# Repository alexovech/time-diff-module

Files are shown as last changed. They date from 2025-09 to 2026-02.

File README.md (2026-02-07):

# LapTimer – Subtraction Module

Team of 5 students.  
My role: subtraction module designer.  
Developed the subtraction module responsible for calculating the time difference between two stopwatch readings.  

---

## Overview
- **Full project description:** [Overview](docs/overview.md)
- **Skills Developed:** Working with Multisim and Ultiboard, designing and testing digital circuits, debugging BCD subtraction logic, and optimizing PCB layout.
- **Features:** BCD-based subtraction, carry/borrow correction, RC-delay capture, setting values through D-type flip-flops and 7-segment display output.
- **Technology:** Texas Instruments 74LS series logic (Full Adders, Flip-Flops, Inverters, XOR/AND/NOR gates).
- **Simulation & PCB:** Designed in [Multisim](schematic/multisim) and [Ultiboard](schematic/pcb) (with 3D projection).

---

## Photo Demonstration
Circuit in Multisim:  
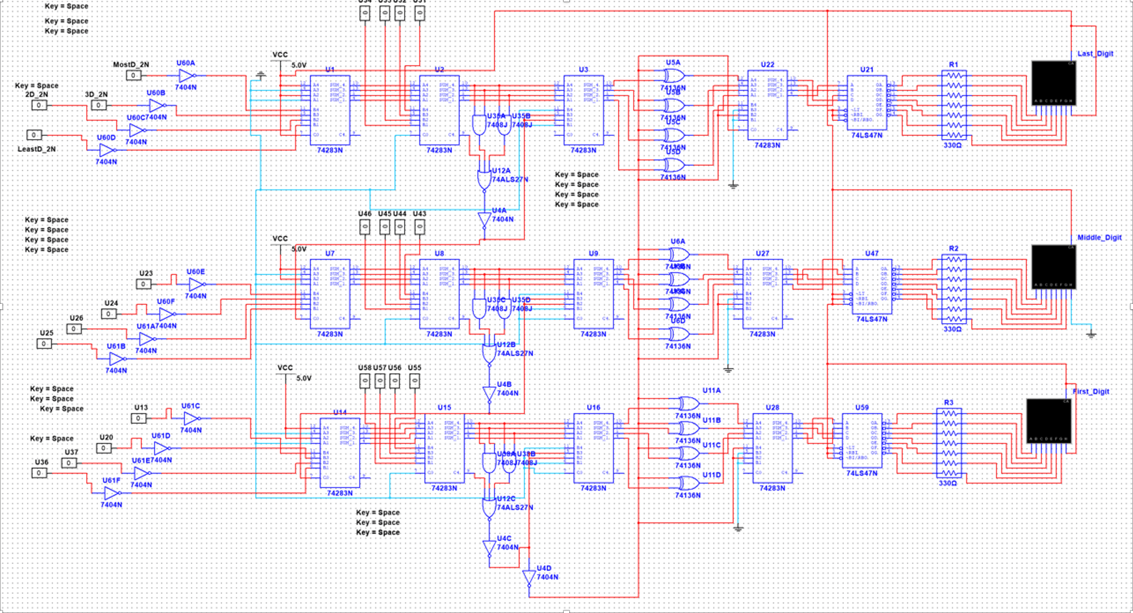
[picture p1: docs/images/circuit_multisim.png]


PCB 3D view (Ultiboard):  
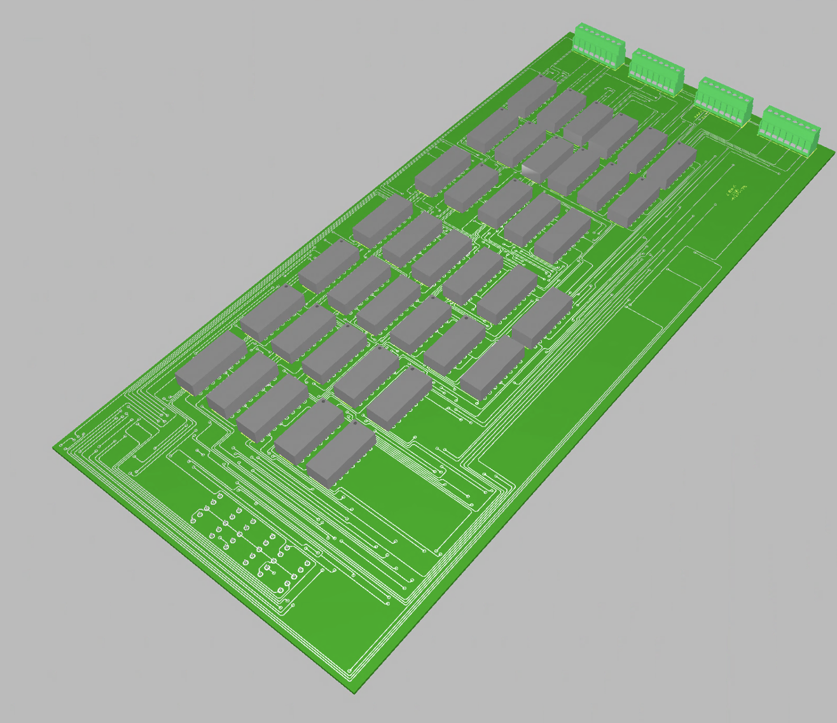
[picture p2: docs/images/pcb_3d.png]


---

## Video Demonstration
System in Action: [▶ Watch on YouTube](https://youtu.be/WPylpVr9RIs)

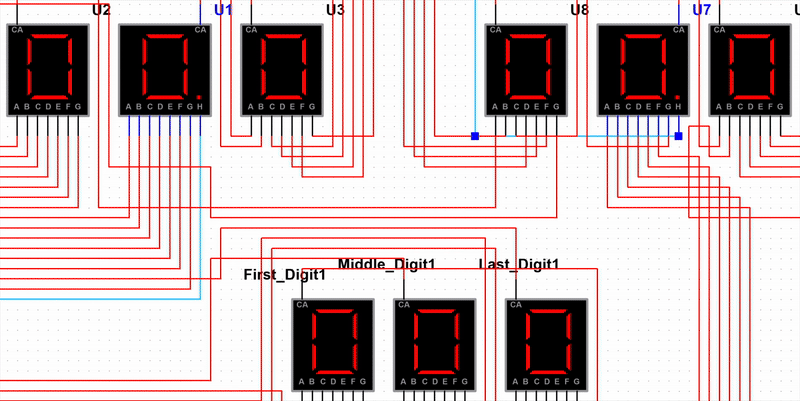
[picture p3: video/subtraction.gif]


---

## Problem-Solving Process
**Full list of challenges and their sollutions:** [Problems & Solutions](docs/problems_solutions.md)

**Example of handwritten notes:**
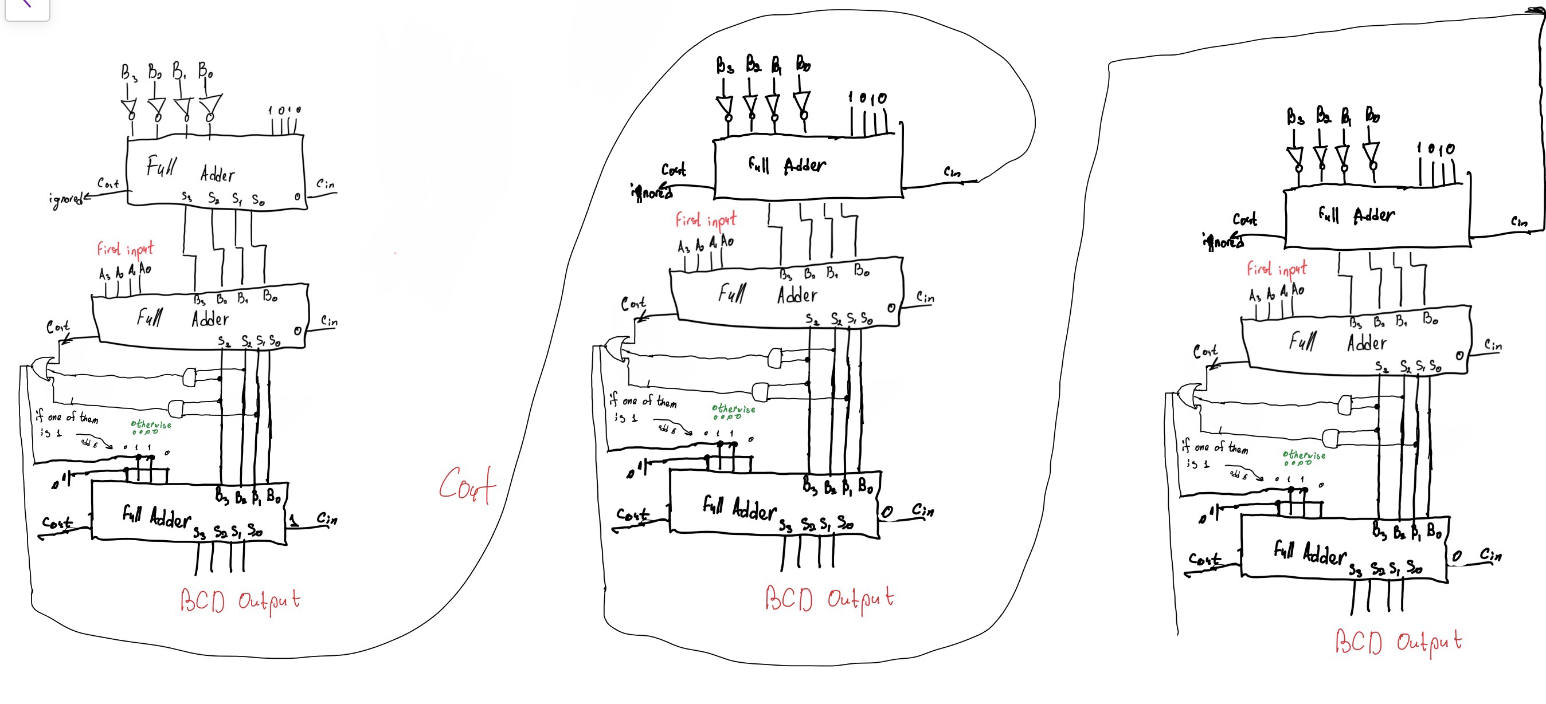
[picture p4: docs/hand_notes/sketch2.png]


➡️ [View rest early calculations and design notes here](docs/hand_notes)

---

## Future Improvements
At this point in development, one of the chief weaknesses in the circuit remains its size.

As this project was done in year one, when both high-level programming concepts and low-level programming concepts had not yet been introduced in class,
The design was purely dependent on hardware logic based on 74LS-series ICs.
But there are quite a few ways in which this system can be improved and minimized in the future:

1. **Microcontroller Integration**

One possible enhancement could be to use a **microcontroller** (like Arduino or ATmega) to create the subtraction logic.
This would enable a single logic IC to replace multifaceted logic ICs. It was intended to simplify wiring and reduce board sizes.

2. **Implementation using VHDL on a PLD/CPLD**

One possible solution using logic design re-engineering would involve redesigning using **Hardware Description Language (VHDL)** to run the logic design on a **programmable logic device (PLD or CPLD)**. This solution would retain the same digital logic design structure for the original project but would improve its speed performance. but with a far smaller footprint, so that everything remains purely hardware-based.

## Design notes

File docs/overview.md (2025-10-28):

The project is a digital stopwatch system for measuring the race laps. The system consists of several interlinked circuits in which every circuit is specially designed to have a specific function in getting an accurate and precise time reading. The **Lap Timer** is the central part of the system in which counting and displaying the passed time are done.

Apart from the stopwatch function, the system also features a **traffic light** red, yellow, and green sequence in advance of a buzzer element providing an auditory cue as race starter. In order to measure completed laps, a **Lap Counter** exsists allowing real-time counting of laps per vehicle. Finally, a **"Subtraction" Circuit** is incorporated to calculate the difference between the time of two drivers and offer the best performance analysis by carrying out the subtraction of the two stopwatches.

With the incorporation of these components, the system provides a structured and effective solution to the calculation of lap time, and as such, it is appropriately placed in racing settings where precision and consistency are very precious.

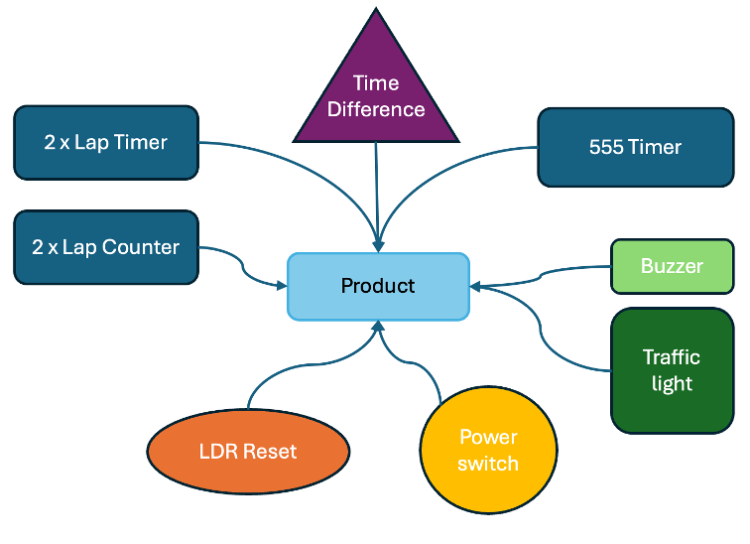
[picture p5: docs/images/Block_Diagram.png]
Block Diagram


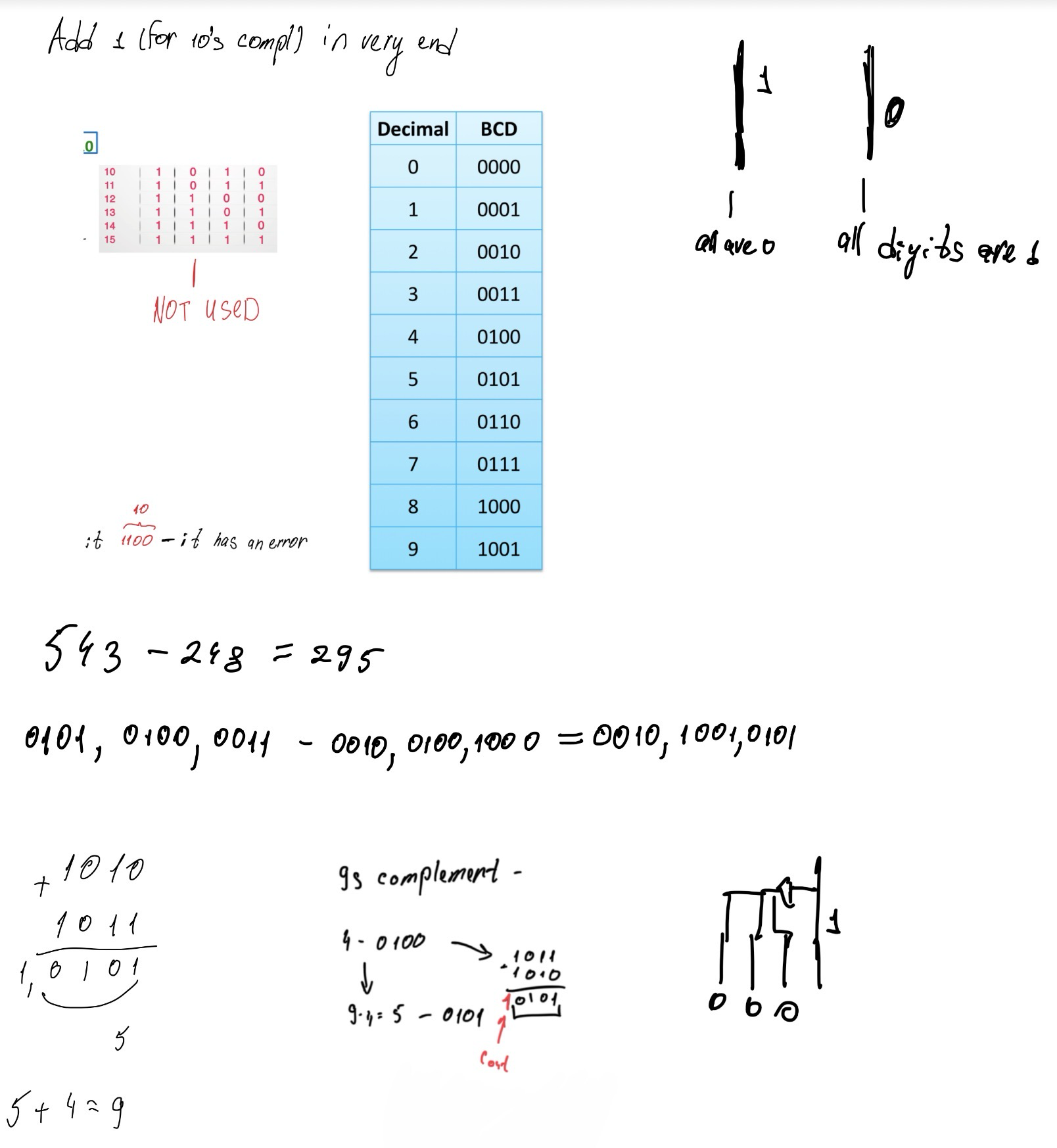
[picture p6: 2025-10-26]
docs/hand_notes/calculation.png

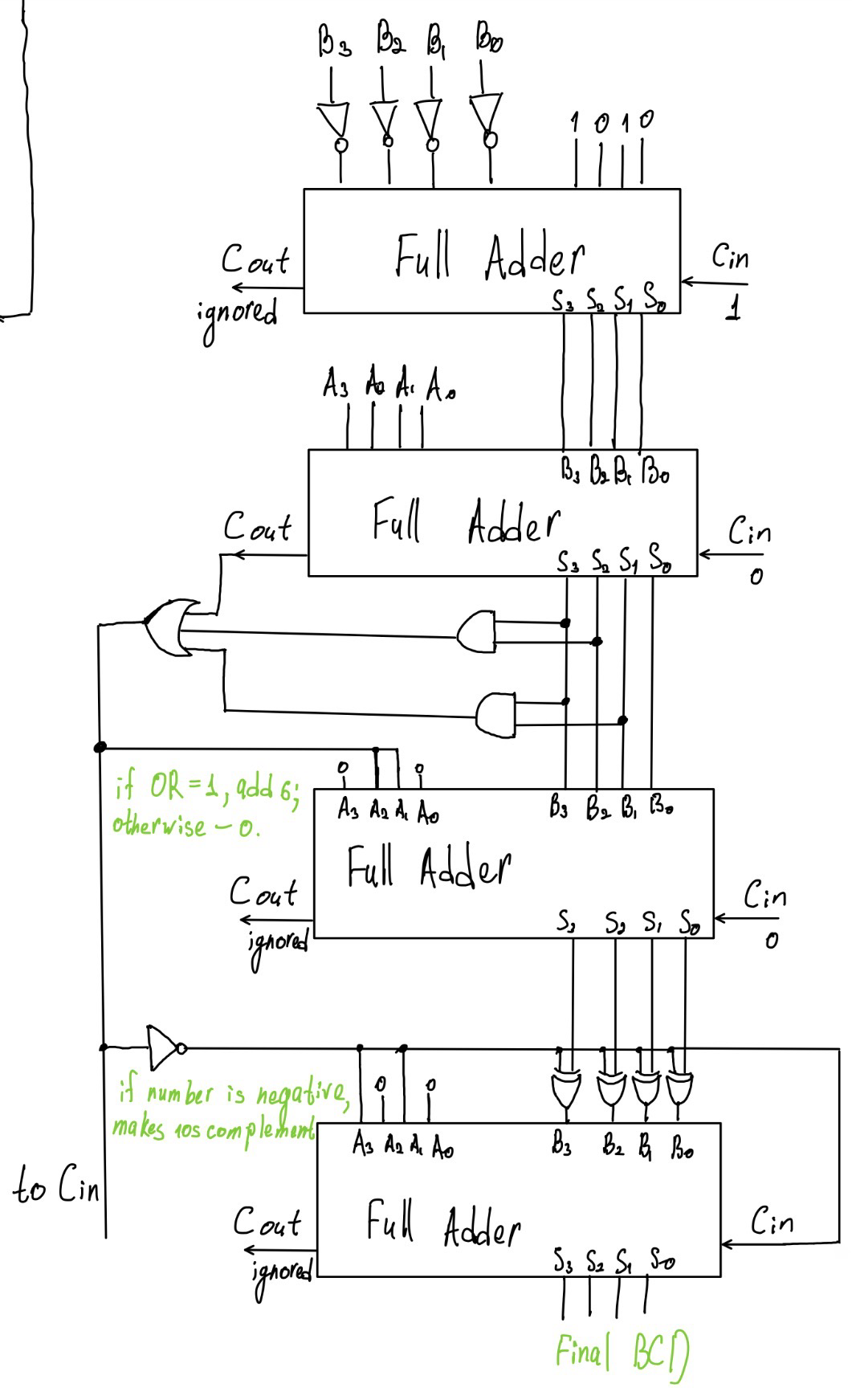
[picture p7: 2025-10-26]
docs/hand_notes/sketch1.png

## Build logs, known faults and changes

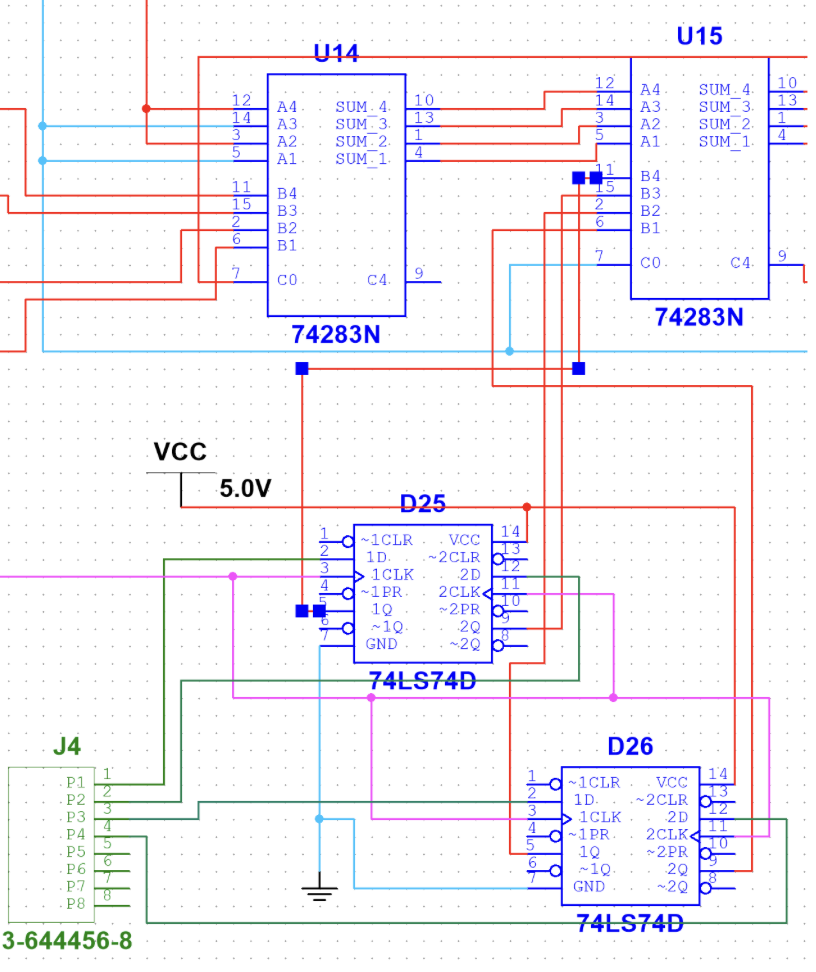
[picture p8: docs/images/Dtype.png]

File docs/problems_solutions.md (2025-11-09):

### Problem 1 - Invalid BCD Output (>9)

**Problem Description:**
In this circuit, during testing, the subtraction sometimes gave results greater than 9, which is invalid in BCD format-for example, 1010₂.
This occurred because carry propagation between adders produced binary sums that exceeded the range of allowed BCD.

**Solution Implemented:**
To rectify this, an extra **Full Adder (SN74LS283)** was implemented to carry out a BCD correction (+6) when the output exceeded 1001₂.

**The principle of working:**
The AND and OR gates formed the detection logic, which would identify when bits D3 and D1 were simultaneously equal to '1', among other combinations of overflows; this created a correction trigger signal.
How It Works Now:
The output from the previous adder forms an invalid BCD pattern (> 1001₂).
the correction logic is triggered, which sends a binary `1010₂` (+6) into the input of the additional adder.
This adder adjusts the value to return it to the valid BCD range of 0 to 9. The correction stage receives `0000₂` if the condition for overflow is false; this leaves the output unchanged. Consequently, every digit remains a valid BCD output irrespective of the carry propagation during subtraction.

---

### Problem 2 - Incorrect Display of Negative Results

**Problem Description:**
In those cases where the subtrahend was larger than the minuend, there was an invalid BCD result, for instance, “997” produced from the subtraction circuit instead of indicating a negative result "003".
In addition, there was no logic related to handling negative values or borrowing in the system.

**Solution Implemented:**
A fourth last Full Adder (SN74LS283), along with a few XOR gates (SN74LS136), was added to check if the result obtained after subtraction was negative.
The XOR phase was receiving signals from both the final **carry-out** signal and the error detection AND gate series. 

**The principle of working:**
Both signals' negative result indicators would cause the XOR gates to invert bits.
As soon as the system recognizes a borrow or an absent carry (logic ‘1’ from detection gates), the XOR function reverses its output bits. As a result, the two’s complement negative value gets transformed into its positive magnitude. Accordingly, instead of printing an invalid number (like 997), the result is corrected to print a valid representation of its absolute value in BCD. The sign itself isn’t shown, but the numerical value remains correct and fixed within the 7-segment display.

---

### Problem 3 - Time Resetting

**Problem Description:**
The subtraction module had to get an automatic signal from the main timer which would trigger the reset for the next measurement of the lap.
However, this reset happened **too fast**, without allowing the circuit to capture and store the last value counted.
This meant that the subtraction step was typically done on incomplete or reset information, making it difficult to obtain precise lap time differences.

**Solution Implemented:**
An **RC circuit** was implemented such that there was a slight delay (on the order of microseconds) between the reset signal and actual timer reset.
Additionally, **D-type flip-flops (SN74LS74AN)** were added to store the output value of the timer immediately before it was cleared.

**The principle of working:**
When the automatic reset signal is triggered, the clock input of the D-type flip-flop activates slightly **before** the timer resets.
This will permit the flip-flop to **latch the final BCD value ** from the output of a timer and hold it steady. The reset pulse reaches the timer after a short delay introduced by the RC network (a few microseconds), clearing its registers for the next lap. This means that the subtraction module always receives the complete final time of the previous lap, thus guaranteeing **precision** and **synchronization** among the measurement cycles.
